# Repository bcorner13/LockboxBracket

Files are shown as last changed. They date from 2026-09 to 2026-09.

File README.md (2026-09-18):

# Lockbox Bracket

A parametric FreeCAD bracket that holds a lockbox **under a desk**: an open-ended U-channel the
box slides into lengthwise, with an outward mounting flange along the top of each side wall
drilled for countersunk M3×10 fasteners that run up into the desk.

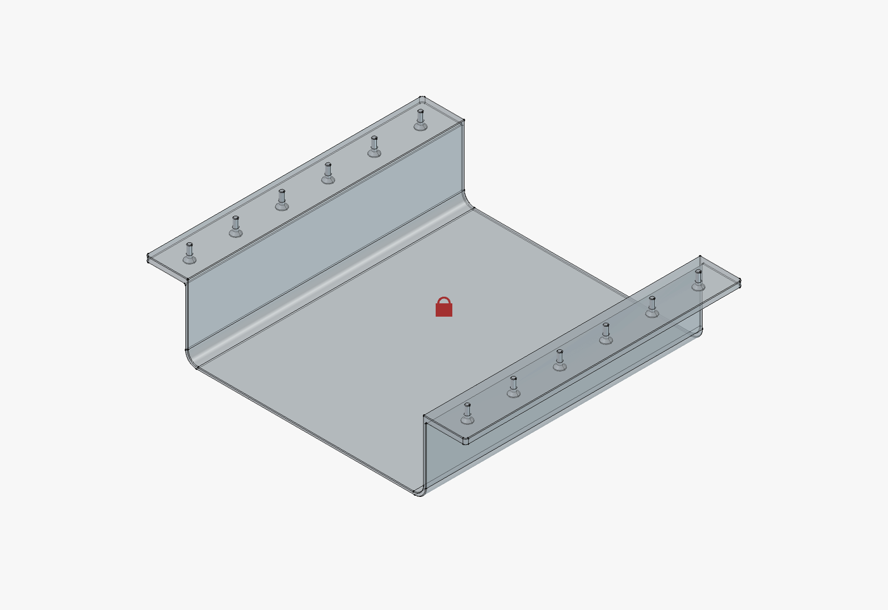
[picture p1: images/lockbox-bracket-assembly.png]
Lockbox Bracket assembly


| | |
|---|---|
| **Envelope** | 225.5 × 185 × 52 mm |
| **Interior cavity** | 165.5 × 185 × 46 mm |
| **Wall / floor** | 2.0 mm |
| **Flanges** | 30 mm wide × 4 mm thick, full depth, both sides |
| **Fasteners** | `NumHoles` × M3×10 countersunk per flange, both flanges (3.4 mm bore, 6.7 mm × 90° c'sink) — **8 total at `NumHoles = 4`** |
| **Volume** | 139 346.02 mm³ |
| **CAD** | FreeCAD 1.1.3, PartDesign, single body + Assembly |

## Status

Model is complete, valid, and **passes the parametric audit**. One watertight solid, all
sketches fully constrained and attached to origin planes, every live dimension bound to the
`VarSet`.

Remediated 2026-09-17: symmetric hole spacing driven by one formula, holes mirrored onto both
flanges via a sketch symmetry constraint, and `2 × NumHoles` screws seated in the bores.
Flexing `NumHoles` returns the volume to its baseline exactly. **`VarSet.Depth` (the channel length, not
`Hole.Depth`) needs care — a large jump can silently drop holes, because the hole's position
uses an unsigned distance constraint. Change it in small steps and re-check the bore count;
see the red warning in `CLAUDE.md`.**

**Width test printed 2026-09-18 — fit confirmed snug, corner radius good, 2 mm walls judged
adequate.** `Depth` then set to 185 mm from the physical box. Full part not yet printed.

> **Retention:** the bracket is deliberately shorter than the box. The box's combination dial
> bottoms against the end of the channel and stops it sliding through — there is no catch.
> Do not lengthen `Depth` to match the box or add a back wall. See [`intent.md`](intent.md).

Test pieces, cheaper than the full part:

| File | Size | Tests |
|---|---|---|
| `stl/Lockbox Bracket-cornertest.stl` | 52 × 31.13 × 52 mm, **5.7%** of the part | M3 screw fit in a horizontal bore, wall + flange thickness, corner fillet |
| `stl/Lockbox Bracket-testcoupon.stl` | 225.5 × 31.13 × 52 mm, **16.8%** | the above **plus the interior width** — does the box drop between the walls |
| `stl/Lockbox Bracket.stl` | full part | — |

Both are cut from the part's **real open end** up to 8 mm past the first hole, so they carry
the genuine end geometry and the true 24.375 mm end margin — the box goes in through the same
opening it will use for real. Full width is the only way to check the box fit; interior width
is **165.50 mm** if you would rather caliper it first.

| Corner test (5.6%) | Width test (16.6%) |
|---|---|
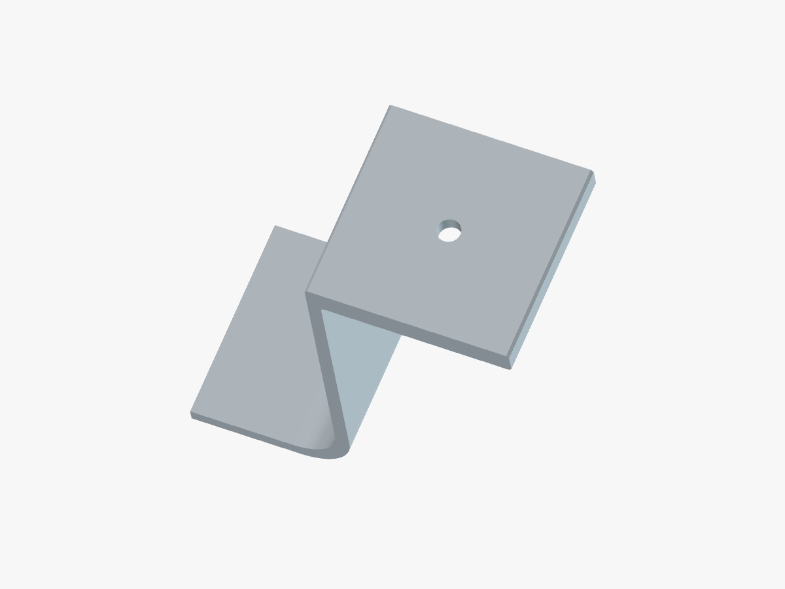
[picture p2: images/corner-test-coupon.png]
Corner test coupon
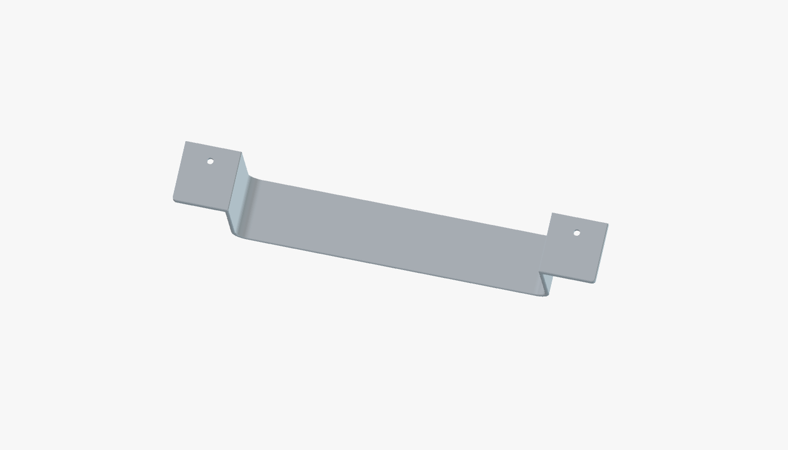
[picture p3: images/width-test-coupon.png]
Width test coupon
|  |  |

Print the test pieces **in the same orientation as production** (depth axis vertical) so the
bores print horizontally exactly as they will in the real part — that is what makes the
screw-fit test meaningful.

`3mf/Lockbox Bracket.3mf` is a Creality Print project carrying the current settings (PETG,
4 walls), but its **geometry is stale** — it predates the drop to 8 holes. Re-import the STL
into that project and re-slice.

## Layout

```
Lockbox Bracket.FCStd     the part — Body plus an in-document VarSet
intent.md                 design goal and constraints (draft — needs confirmation)
plan.md                   remediation plan; execution waits on approval
CLAUDE.md                 project rules, assembly architecture, known traps
3mf/                      slicer-ready print files
stl/                      STL exports
gcode/                    slicer output (gitignored, regenerable)
images/                   renders and screenshots
macros/                   project .FCMacro files
scripts/audit_parametric.py   parametric compliance audit
```

## Exporting print files

Run `macros/export_print_files.FCMacro`. It writes `stl/Lockbox Bracket.stl` and
`3mf/Lockbox Bracket.3mf` from the bracket **Body only**.

> **Do not export with the Assembly selected.** The community
> `3D_Printer_3mf_Workflow.FCMacro` exports the current selection, so it will mesh the twelve
> M3×10 screws into the print file. `export_print_files` pins the selection to `Body` and
> leaves it selected, so you can run the workflow macro straight afterwards for its
> slicer-settings round-trip.

## Changing the hole count

`NumHoles` drives the spacing, both flanges, and the screws. After changing it:

1. Recompute the Body — the bores re-space symmetrically on their own.
2. Re-run `macros/place_screws.FCMacro` so the screw set matches the new bore count. It reads
   bore positions from the solid, so it cannot drift from the geometry.

There is **no `Params.FCStd`** — this single-document project deliberately keeps its VarSet
in-document. See the deviation note in [`CLAUDE.md`](CLAUDE.md) before "fixing" that.

## Working on this model

Open the FCStd in FreeCAD and drive everything from the `VarSet`. Never edit sketch
coordinates directly — adjust the driving variable or add a constraint bound to one.

Before committing any change:

```bash
python3 scripts/audit_parametric.py
```

A clean audit is necessary but not sufficient — the script has documented blind spots listed
in `CLAUDE.md`.

Conforms to `PROJECT_BOOTSTRAP.md` and `CAD_STANDARDS.md` in the parent workspace.

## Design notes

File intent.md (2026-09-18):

# Intent — Lockbox Bracket

Stated by Bradley 2026-09-17/18. Test-print validated 2026-09-18.

## Goal

A bracket that holds a lockbox **under a desk**, fixed with **M3×0.5 screws (M3×10,
ISO14582 countersunk)**.

The box sits in an open-ended U-channel; a mounting flange runs along the top of each side
wall. The flanges go up against the underside of the desk and the screws pass **up through
the flanges into the desk** — heads countersunk flush on the flange underside, ~6 mm of
thread into the desk through the 4 mm flange.

## How the box is retained — the key design decision

**The bracket is deliberately SHORTER than the box.** The box slides in from one open end,
and the **combination dial / lock knob on the box's front face bottoms out against the end of
the channel**, stopping it before it can slide all the way through. There is no catch, lip, or
stop feature in the model — the knob *is* the stop.

This is why `VarSet.Depth` is **185 mm** rather than matching the box's length. That number
came off the physical box (2026-09-18) and is not arbitrary:

> **Do not "tidy" `Depth` to match the box length, and do not add a back wall.** Either would
> defeat the retention mechanism. If the bracket were as long as the box, the knob would clear
> the end and the box would slide straight through.

The far end stays open so the box can be pushed back out.

## Requirements

1. **Hole placement symmetric** along the flange. ✅ done — one formula, equal end margins.
2. **`NumHoles` is a parameter**; spacing, both flanges and the screws all follow from it.
   ✅ done. Currently 4 per flange, **8 total** (12 was judged overkill).
3. **Both flanges drilled.** ✅ done via a sketch symmetry constraint.
4. **Screws seat in the holes**, heads in the countersinks, threads up into the desk. ✅ done.

## Form (measured)

- Open-ended **U-channel**: 2 mm floor, two 2 mm side walls, open at both ends.
- Interior cavity **165.5 × 185 × 46 mm**; overall envelope **225.5 × 185 × 52 mm**.
- **Flanges** 30 mm wide × 4 mm thick, full length, at the top of each wall.
- **Countersunk M3 clearance holes**: 3.4 mm bore, 6.7 mm × 90° countersink, opening downward.

## Validated by test print (2026-09-18)

A full-width coupon (225.5 × 32.4 × 52 mm, 16.6% of the part, 48m49s, 29.4 g PETG) was printed
in the production orientation and checked against the real box:

- **Fit is snug without being over-tight** — the interior width of 165.5 mm is correct.
- **The corner radius fits well** — estimated value confirmed, no change needed.
- **2 mm walls and floor are adequate.** Bradley's call: *"plenty strong as is."* The earlier
  open question about thickening for the load case is **closed** — no change.

## Constraints

- Must follow `CAD_STANDARDS.md` and the parametric rules in `CLAUDE.md`.
- All dimensions in mm; single watertight manifold solid.
- Printable **without supports** — printed on end, depth axis vertical.
- Fits the Creality K2 Plus bed (350 × 350 mm).
- **Material: PETG** (CR-PETG, CFS slot 4), 4 perimeters. Chosen over PLA/PLA-CF because the
  bracket carries a load continuously and PLA creeps under sustained stress.
- Target price point $36–$45 per `CAD_STANDARDS.md`. Material cost is a few dollars; the full
  part is ~139 cm³.

## Non-goals

- **No lid, latch, catch or back stop** — the box's own lock knob is the stop (see above).
- No print-in-place moving parts.
- The desk itself is not modelled.

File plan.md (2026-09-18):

# Plan — Lockbox Bracket

**Status: EXECUTED 2026-09-17.** All steps applied via the two macros, validated, and saved.
Audit clean; parametric flex verified. Kept as the record of what was changed and why.

Remediation of an existing model — not an initial build.

### Result

| Check | Result |
|---|---|
| Audit | ✅ 0 issues |
| Bores | 12 (`2 × NumHoles`), both flanges, uniform 32.5 mm pitch, **equal 16.25 mm end margins** |
| Screws | 12 M3×10 seated, max axis offset **0.000 mm**, heads at z = 48, all in `Assembly.Group` |
| Solid | valid, 1 solid, 146 686.19 mm³, 225.5 × 195 × 52 mm |
| Flex test | `NumHoles` 6→8 gives 16 symmetric bores; 8→6 restores 146 686.19 mm³ **exactly** |

> **Later changes — this table records the state at remediation, not today.**
> - 2026-09-17: `NumHoles` 6 → **4** (8 bores total; 6/flange judged overkill). Current volume
>   146 908.44 mm³, pitch 48.75 mm, end margins 24.375 mm, 8 screws.
> - 2026-09-17: **`VarSet.Depth` found NOT safely parametric.** That is the part's length
>   along Y — *not* `Hole.Depth`, which is correctly bound to `FlangThickness` and is fine.
>   The flex test above covered `NumHoles` and `OuterFilletRadius` but never `VarSet.Depth`.
>   A large jump in it silently drops holes: `Sketch003.Constraints[2]` is an **unsigned
>   `Distance`**, which has an inboard and an outboard solution, and the solver takes the one
>   nearer the current geometry. Path-dependent — 195→100 in one jump gives 6 bores, the same
>   destination in 20 mm steps gives 8. The expression arithmetic is correct and the external
>   reference does track; an earlier note here blamed the reference and was wrong. Unfixed;
>   the fix is a signed `DistanceY` from the sketch origin. See `CLAUDE.md`.

---

## Intake audit — what was measured

Read via the FreeCAD MCP bridge (1.1.3, GUI, xmlrpc). Measured, not inferred.

**Healthy:** one valid manifold solid, 147 019.56 mm³, 225.5 × 195 × 52 mm, no object in an
error state, all 4 sketches `FullyConstrained = True`, all attached to **origin planes**,
13 expressions already bound including both `AttachmentOffset.Base.z` offsets.

**Defects:**

| # | Object | Property | Value | Problem |
|---|---|---|---|---|
| 1 | `Fillet` | `Radius` | 8.0 mm | Hard-coded. Flagged by audit. |
| 2 | `Chamfer` | `Size` | 0.4 mm | Hard-coded. Flagged by audit. |
| 3 | `Hole` | `Diameter` | 3.4 mm | ~~Hard-coded~~ **WITHDRAWN.** Property is `ReadOnly` — derived from `ThreadSize = M3x0.5` + `ThreadFit = Medium` (ISO 273 medium clearance → 3.4 mm). Cannot be bound, and should not be: the standard is the driver. |
| 4 | `Hole` | `HoleCutDiameter` / `HoleCutCountersinkAngle` | 6.7 mm / 90° | ~~Hard-coded~~ **WITHDRAWN.** Auto-computed from the ISO countersink table while `HoleCutCustomValues = False`. Binding them would require forcing custom values, freezing the countersink off-standard. |
| 5 | `VarSet.HoleDiameter` | — | 4.0 mm | **Dead knob** — drives only the `Sketch003` marker circle, which `PartDesign::Hole` ignores (the sketch supplies positions; the bore comes from `ThreadSize`). Proof: marker Ø4.0, measured bore Ø3.4. |
| 6 | `Sketch003` + `LinearPattern` | spacing | — | **Three divisors for one concept** (below). |
| 7 | `Sketch003` / `Hole` | — | — | **Holes on one flange only** (all 6 bores at x = +97.75). |
| 8 | 6 × `Screw00n` | `Placement` | — | **Screws not seated.** Five are stacked at (−3.25, 0, 0); one at (54.12, −108.204, 0). None is at a bore. They are also **outside** `Assembly.Group`. |
| 9 | `Joint` ("Fixed") | `Reference1/2` | `None` | Empty, non-functional joint. |

### Defect 6 in detail

```
Sketch003.Constraints[2] = Depth / NumHoles            = 32.5     (first-hole offset)
LinearPattern.Length     = Depth - Depth/(NumHoles-2)  = 139.286  (span)
LinearPattern.Offset     = Depth / (NumHoles + 1)      = 27.857   (inert in Length mode)
```

Measured bores at y = −65, −37.143, −9.286, 18.571, 46.429, 74.286: uniform 27.857 mm pitch
but **end margins of 32.5 vs 23.21 mm**. `NumHoles - 2` also divides by zero at `NumHoles = 2`.

### Additional fragility (not remediated — documented only)

Three sketches use **external geometry from feature faces**: `Sketch001`→`Pad.Face1`,
`Sketch002`→`Pocket.Face6/Face12`, `Sketch003`→`Pad001.Face13`. Attachment is clean, so this
is a topological-naming risk, not a DAG cycle. Left alone deliberately: re-cutting these
references would disturb working, fully-constrained sketches for no functional gain.

---

## PARAMETERS

`VarSet` stays **in-document** (deliberate deviation — see `CLAUDE.md`), local `VarSet.Name` form.

### Existing (unchanged)

`Width` 169.5 · `Depth` 195.0 · `WallHeight` 48.0 · `WallThickness` 2.0 · `CornerRadius` 7.0 ·
`FlangWidth` 30.0 · `FlangThickness` 4.0 · `FlangRadius` 2.0 · `NumHoles` 6

### To add

| Name | Type | Value | Drives |
|---|---|---|---|
| `OuterFilletRadius` | `App::PropertyLength` | 8.0 mm | `Fillet.Radius` — distinct from `CornerRadius` (7.0); separate concept, separate knob (global rule #5) |
| `ChamferSize` | `App::PropertyLength` | 0.4 mm | `Chamfer.Size` |
| `ScrewLength` | `App::PropertyLength` | 10.0 mm | screw generation (M3×10) |

No countersink Params: those dimensions are standard-derived (defects 3–4, withdrawn).

### To rename

`HoleDiameter` → **`HoleMarkerDia`** (stays 4.0 mm). The variable is real but its name lies:
it sizes the `Sketch003` marker circle, which only supplies hole *positions*. The actual bore
is set by `Hole.ThreadSize = M3x0.5` with `ThreadFit = Medium`. Renaming it is the honest fix —
"one knob, one concern" (global rule #5) — and stops a future session from "correcting" it to
3.4 mm in the belief that it drives the bore. `Sketch003.Constraints[0]` is rebound to the new
name; the old property is removed.

**Bolt-hole clearance** therefore has no Param of its own by design: it is delegated to the ISO
fit class on the `Hole` feature. Recorded in `CLAUDE.md` so rule #4 is not read as violated.

---

## FEATURE TREE

No features added, removed, or reordered. Tip stays `LinearPattern`.

```
Body
├── Sketch         (XY_Plane)   footprint          → Width, Depth
├── Pad            48                              → WallHeight
├── Fillet         2 edges                         → OuterFilletRadius        [BIND]
├── Sketch001      (XZ_Plane)   wall section       → WallThickness ×3, CornerRadius
├── Pocket         UpToFace Fillet.Face1
├── Sketch002      (XY_Plane @ z=WallHeight)       → FlangWidth, FlangRadius
├── Pad001         4                               → FlangThickness
├── Mirrored       about Sketch002 V_Axis          (second flange)
├── Chamfer        12 edges                        → ChamferSize              [BIND]
├── Sketch003      (XY_Plane @ z=WallHeight)       → HoleDiameter, FlangWidth/2, spacing
│                  + SECOND CIRCLE mirrored about V_Axis                      [ADD]
├── Hole           M3 c'sunk, Depth=FlangThickness → HoleDiameter, HoleCsink* [BIND]
│                  Profile widened from Edge1 to the whole sketch             [CHANGE]
└── LinearPattern  → NumHoles, symmetric span                                 [REVISE]
```

## CONSTRAINT STRATEGY

1. **No existing sketch geometry is touched**; no coordinate edits (global rule #2). All four
   sketches stay fully constrained.

2. **Bindings via `setExpression`** on feature properties: `Fillet.Radius` →
   `OuterFilletRadius`, `Chamfer.Size` → `ChamferSize`. The `Hole` feature's dimensions are
   left to the ISO standard (defects 3–4 withdrawn) and recorded as audit exemptions.

3. **Symmetric spacing** — one concept, one formula.

   `LinearPattern.Mode` is **`Spacing`**, so `Offset` is the live driver and `Length` is
   inert. (Both happened to evaluate to 27.857, which is why the two are easy to confuse —
   the mode had to be read to tell them apart.)

   ```
   Sketch003.Constraints[2] = Depth / (2 * NumHoles)   = 16.25   (half-pitch end margin)
   LinearPattern.Offset     = Depth / NumHoles         = 32.5    (pitch)     [LIVE]
   LinearPattern.Occurrences= NumHoles                           (unchanged)
   LinearPattern.Length     — expression cleared                 (inert; contradictory)
   ```

   First bore at 16.25 from the near edge, last at 16.25 + 5 × 32.5 = 178.75, leaving
   195 − 178.75 = **16.25 at the far edge — equal margins**. No `NumHoles - 2` term, so it
   stays valid down to `NumHoles = 1`.

4. **Mirror the holes onto the second flange** by adding a second circle to `Sketch003`,
   constrained `Symmetric` about the sketch V_Axis and `Equal` to the first — rather than by
   adding a `Mirrored`/`MultiTransform` feature. Reasons: the flanges are already symmetric
   about x = 0, a sketch-level symmetry constraint is inherently parametric, it keeps the
   feature tree flat, and it avoids chaining one transform feature onto another (which
   PartDesign does not support without `MultiTransform`). `Hole.Profile` is widened from
   `Edge1` to the whole sketch so both circles are drilled; `LinearPattern` then patterns both.
   Result: **2 × NumHoles = 12 bores.**

5. **Screws seated in the bores.** The head of an ISO14582 screw sits at its placement origin
   with the shank running local −Z (verified from the shape: local z ∈ [−10, 0]). With a 180°
   rotation about X the shank points +Z. So each screw gets
   `Placement = (x_bore, y_bore, WallHeight)`, rotation 180° about X — head top flush with the
   flange underside at z = 48, thread running up through the 4 mm flange and ~6 mm into the desk.
   The screw set is regenerated to `2 × NumHoles`, and the screws are moved **into**
   `Assembly.Group`.

6. **Delivery:** two reviewable, idempotent macros under `macros/` (global rule #7 — no typed
   MCP tool covers `setExpression`, sketch symmetry constraints, or Fasteners-WB object
   creation):
   - `remediate_parametric.FCMacro` — steps 1–4
   - `place_screws.FCMacro` — step 5; re-run after any change to `NumHoles`

---

## TOOLING FIX

`scripts/audit_parametric.py` checks only `Length/Length2/Radius/Offset/Size`, so
`PartDesign::Hole` is effectively unaudited — defects 3 and 4 passed a "clean" run. This
project's copy gains `Diameter` and `Depth` coverage. The root canonical copy is **not**
edited (standing instruction). This is a third bug in that script, after the two in memory.

---

## VALIDATION

1. `python3 scripts/audit_parametric.py` → 0 issues.
2. Recompute → no object in an error or touched state.
3. `isValid() == True`, exactly 1 solid in the Body.
4. **Bore census:** exactly `2 × NumHoles` = 12 bores of Ø3.4, at x = ±97.75, with **equal
   end margins** (16.25 mm) and uniform 32.5 mm pitch — re-measured from `Shape.Faces`.
5. **Screw census:** 12 screws, each within 0.01 mm of a bore axis, head top at z = 48.
6. **Parametric proof:** set `NumHoles` 6 → 8, recompute, confirm 16 symmetric bores; flex
   `OuterFilletRadius` 8 → 6; restore both and confirm volume returns to the pre-change
   baseline of 147 019.56 mm³ **exactly**.
7. Steps 1–2 and the bindings must not move material; only the spacing fix and the mirrored
   flange may change volume, and only by relocating/adding bores.

Nothing is saved until validation passes (`PROJECT_BOOTSTRAP.md` Step 6).

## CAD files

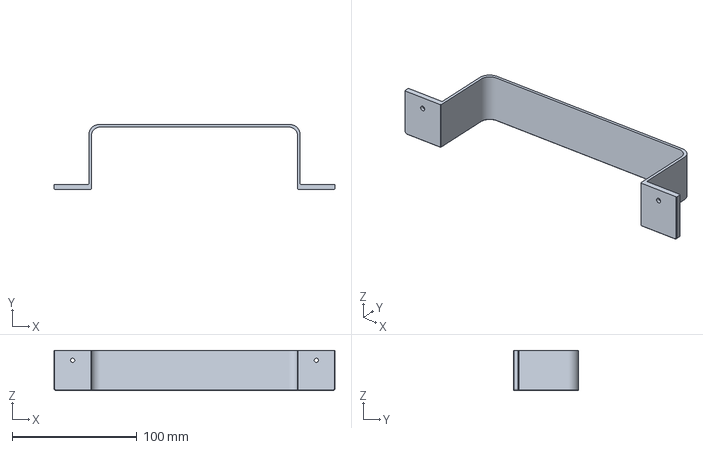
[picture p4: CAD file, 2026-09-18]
3mf/Lockbox Bracket-widthtest.3mf
225.5 x 52.0 x 32.4 mm

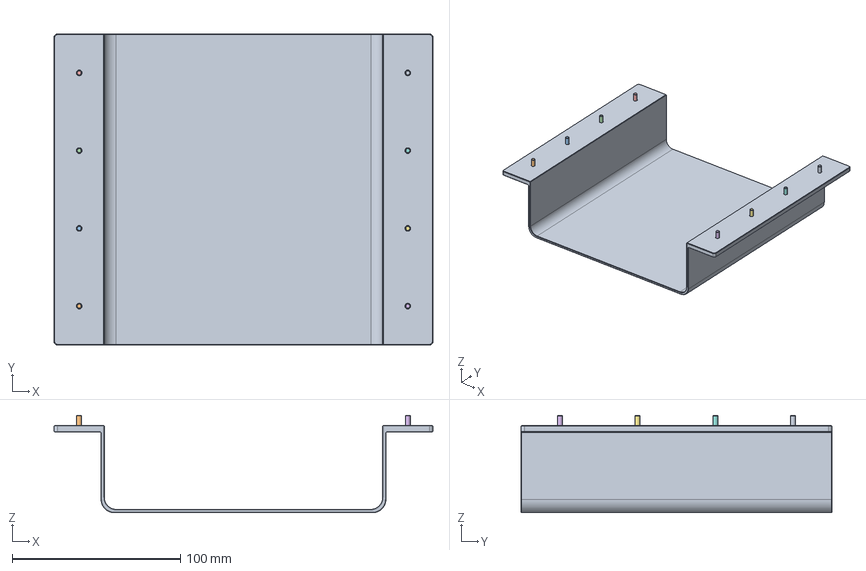
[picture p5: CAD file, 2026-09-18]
Lockbox Bracket.FCStd
225.5 x 185.0 x 58.0 mm
M3x10-Screw
M3x10-Screw018
M3x10-Screw019
M3x10-Screw020
M3x10-Screw021
M3x10-Screw022
M3x10-Screw023
M3x10-Screw024

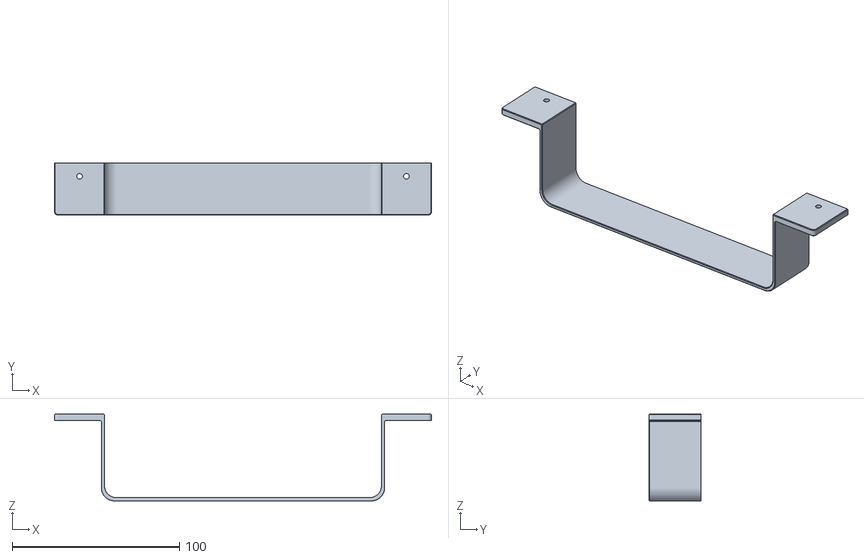
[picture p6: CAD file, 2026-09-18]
stl/Lockbox Bracket-testcoupon.stl
225.5 x 31.1 x 52.0

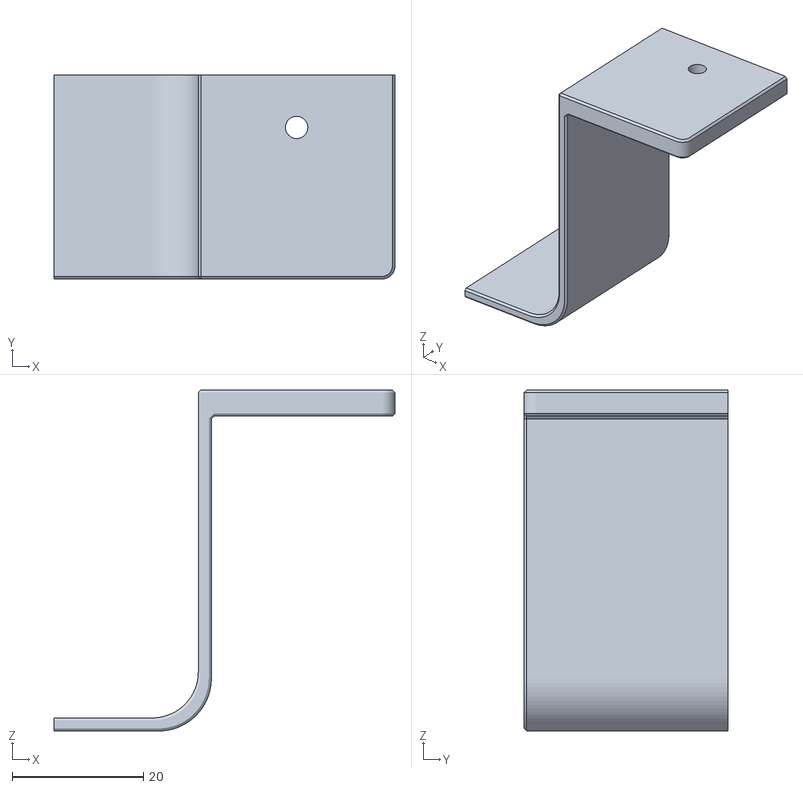
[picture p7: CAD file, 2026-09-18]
stl/Lockbox Bracket-cornertest.stl
52.0 x 31.1 x 52.0

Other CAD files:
3mf/Lockbox Bracket.3mf
stl/Lockbox Bracket.stl

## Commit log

2026-09-18 Bootstrap project structure per PROJECT_BOOTSTRAP.md
    Existing rough model brought under the workspace standard. Structure only —
    no geometry was modified.
    - Required layout: 3mf/ stl/ gcode/ images/ macros/ scripts/
    - Standards copied verbatim from the workspace root (CAD_STANDARDS,
    MCP_TOOLS_REFERENCE, tools)
    - .claude/settings.json guard hook committed; .gitignore ignores only
    .claude/settings.local.json so the hook travels with the repo
    - audit_parametric.py sourced from the MagicCardBox copy, which carries fixes
    for both known enum bugs in the canonical script
    - Sliced 3MF moved to 3mf/
    - CLAUDE.md, intent.md, plan.md, README.md written from the measured state of
    the model
    In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
    [Lockbox Bracket.3mf, Lockbox Bracket.FCStd]
2026-09-18 Add Assembly with M3x10 countersunk screws (user-authored)
    Assembly::AssemblyObject with Body001 link, GroundedJoint, and six
    ISO14582 M3x10 screws. Checkpointed as received, before parametric
    remediation. Screws are not yet positioned in the bores.
    [Lockbox Bracket.FCStd]
2026-09-18 Remediate parametric model: symmetric holes, both flanges, screws seated
    Intent captured from Bradley: an under-desk lockbox bracket fixed with
    M3x0.5 (M3x10 ISO14582 countersunk) screws.
    Model changes, via two idempotent macros:
    - Add Params OuterFilletRadius, ChamferSize, ScrewLength; bind Fillet.Radius
    and Chamfer.Size
    - Rename the dead knob HoleDiameter -> HoleMarkerDia. It sizes the Sketch003
    marker circle only; PartDesign::Hole uses the sketch for POSITIONS and cuts
    at its own ReadOnly Diameter, derived from ThreadSize + ThreadFit
    - Fix the hole spacing. Three expressions described one concept with three
    divisors (one dividing by NumHoles-2, undefined at NumHoles=2), leaving e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
    [Lockbox Bracket-v1-pre-remediation.3mf, Lockbox Bracket.FCStd]
2026-09-18 Export printable geometry only; add export_print_files macro
    The community 3D_Printer_3mf_Workflow macro exports FreeCADGui.Selection, so
    running it with the Assembly selected meshed all twelve M3x10 screws into the
    3MF - a ~20 MB file no slicer can use.
    - Add macros/export_print_files.FCMacro: meshes Body.Tip alone (linear
    deflection 0.05, angular 10 deg) and writes stl/ + 3mf/. It refuses to run on
    an invalid shape or anything other than exactly one solid, and leaves Body
    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
    [Lockbox Bracket-v1-pre-remediation.3mf, Lockbox Bracket.3mf, Lockbox Bracket.stl]
2026-09-18 Use the Creality Print slicer project as the 3mf deliverable
    Bradley re-exported from the Body instead of the Assembly, then saved a
    Creality Print project. Verified printable: one object, 20284 vertices,
    z span 52.00 mm (screws would add ~6 mm), so no fasteners in the geometry.
    - 3mf/Lockbox Bracket.3mf is now that slicer project, carrying its print
    settings, rather than a bare FreeCAD geometry export
    - export_print_files.FCMacro writes the STL only. 3mf/ holds slicer projects
    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
    [Lockbox Bracket.3mf]
2026-09-18 Slicer: switch to PETG and raise walls to 4
    Edited 3mf/Lockbox Bracket.3mf in place; geometry untouched (20284 vertices,
    z span 52.00 verified before and after).
    - Object extruder 1 -> 4, i.e. Hyper PLA-CF -> CR-PETG. PLA creeps under
    sustained load and this bracket carries a lockbox continuously; PLA-CF is
    also brittle against the shock of a box dropped into the channel
    - wall_loops 2 -> 4. The flanges are 4 mm along part Z, which is horizontal in
    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
    [Lockbox Bracket.3mf]
2026-09-18 Drop to 8 holes; add small corner test piece; flag Depth as unsafe
    NumHoles 6 -> 4 per flange (8 total, down from 12). Verified: 8 bores, uniform
    48.75 mm pitch, symmetric 24.375 mm end margins, valid single solid,
    146908.44 mm3, audit clean. Screws resynced to 8 and exports regenerated.
    Test pieces, both cut from the finished solid with a boolean common so the
    production model is never touched:
    - stl/Lockbox Bracket-cornertest.stl - 52 x 30 x 52 mm, one wall + flange +
    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
    [Lockbox Bracket-cornertest.stl, Lockbox Bracket-testcoupon.stl, Lockbox Bracket.FCStd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]
2026-09-18 Docs: disambiguate Hole.Depth from VarSet.Depth
    Bradley flagged that Depth is tied to the flange thickness. Correct, and it
    exposed an ambiguity in my own warning: two unrelated properties share the
    word.
    Hole.Depth = 4.0 mm, bound to VarSet.FlangThickness - how deep the bore
    drills. Healthy, verified still bound.
    VarSet.Depth = 195 mm, the channel length along Y - the one whose change
    silently deletes every hole.
    The red warning said only "Depth", which reads as the former. Every reference
    in CLAUDE.md, plan.md and README.md is now qualified, and CLAUDE.md leads the
    Known debt section with an explicit note distinguishing the two.
    No model chang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
2026-09-18 Correct the VarSet.Depth diagnosis: unsigned constraint, not a bad reference
    Bradley pushed back that the spacing expression is pure maths and should not
    care about length. He was right, and my earlier explanation was wrong.
    Measured, same destination by two routes:
    jump 195 -> 100 value 12.5, circle y = -62.5 (outside), 6 bores
    steps 195->180->...->100 value 12.5, circle y = -37.5 (correct), 8 bores
    Identical arithmetic, different outcome, so the cause is path-dependence in
    the solver - not the expression and not the external reference.
    Real cause: Sketch003.Constraints[2] is an UNSIGNED Distance to an edge.
    "16.25 mm from that edge" has an inboard and an outboard s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
2026-09-18 Trim the width test coupon from 48.75 mm to 25 mm deep
    The corner piece cannot test the interior width - only a full cross-section
    can. But that coupon was one full hole pitch deep, which is more material
    than the test needs.
    width test: 225.5 x 25 x 52 mm, 18795 mm3, 12.8% of the part (was 25%)
    corner test: unchanged, 52 x 30 x 52 mm, 5.2%
    Full width is non-negotiable; the depth is now the minimum that still carries
    a bore in each flange and stays stiff enough not to flex and give a false fit
    reading. Both remain watertight, single-solid, cut from the finished solid
    with a boolean common - the production model is untouched (verified: Depth
    195, NumHoles 4, 8 bores, audit clean).
    Also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
    [Lockbox Bracket-cornertest.stl, Lockbox Bracket-testcoupon.stl]
2026-09-18 Cut test pieces from the real end, stopping past the first hole
    Both pieces were slabs taken from the middle of the part, which meant two
    artificial cut faces and a hole sitting centrally rather than at its true end
    margin. They now run from the part's real open end to 8 mm past the first
    bore, so they carry the genuine end geometry and the true 24.375 mm end
    margin - and the box goes in through the same opening it will use for real.
    corner test: 52 x 32.38 x 52 mm, 8234 mm3, 5.6% of the part, 1 bore
    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
    [Lockbox Bracket-cornertest.stl, Lockbox Bracket-testcoupon.stl]
2026-09-18 Add sliced width-test project (PETG, 4 walls, 48m49s)
    3mf/Lockbox Bracket-widthtest.3mf - the width-test coupon sliced with the
    production settings, currently printing.
    Built by grafting the coupon mesh into a copy of the main slicer project:
    same object structure, same build rotation matrix, translation Z set to
    16.1875 (half the 32.375 mm post-rotation height). The CLI wrapper
    ~/bin/creality-slice needs a 3MF project - a bare STL falls back to a default
    profile and fails validation, and --load-settings rejects a project-exported
    JSON as "from project unsupported".
    Verified from the G-code header rather than assumed:
    filament used [g] = 0.00, 0.00, 0.00, 29.40 -> slot 4 PETG only
    wa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
    [Lockbox Bracket-widthtest.3mf]
2026-09-18 Depth 195 -> 185 from the box; record the knob-as-stop retention design
    Width-test coupon printed 2026-09-18 in PETG at 4 walls. Result: fit snug
    without being over-tight, corner radius good as estimated, and 2 mm walls and
    floor judged adequate - "plenty strong as is". The open load-case question is
    closed; no thickening.
    Depth set to 185 mm, measured off the physical box.
    RETENTION - the design decision that cannot be recovered from geometry:
    the bracket is deliberately SHORTER than the box. The box slides in and its
    combination dial / lock knob bottoms against the end of the channel, which is
    what stops it sliding through. There is no catch or stop feature - the knob is
    the stop. Length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
    [Lockbox Bracket-cornertest.stl, Lockbox Bracket-testcoupon.stl, Lockbox Bracket.FCStd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]
2026-09-18 Correct the print orientation note: on end, not flat
    CLAUDE.md claimed 'channel open-side-up, flanges flat on the bed', written
    before the slicer project was examined. Wrong, and the opposite of what is
    being printed. The part prints ON END with the 185 mm length vertical -
    confirmed by the build transform and by max Z in the G-code. Flat would leave
    the flanges as 4 mm horizontal cantilevers at z=48 needing support; on end
    needs none.
    Added the consequence that matters for the proposed diamond cutouts:
    print-vertical is part Y, so a cutout that looks self-supporting in the CAD
    view can be lying on its side in the print. Rule recorded: for half-diagonal
    a along part Y and b across it, overh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
